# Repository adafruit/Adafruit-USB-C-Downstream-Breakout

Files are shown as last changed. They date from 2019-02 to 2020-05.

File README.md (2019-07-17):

## Adafruit USB C Breakout Board - Downstream Connection PCB

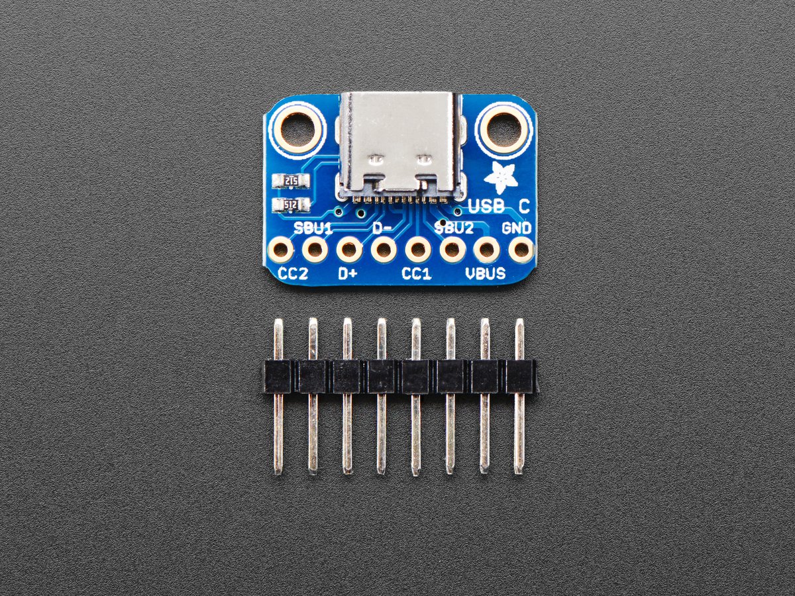
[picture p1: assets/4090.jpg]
<a href="http://www.adafruit.com/products/4090"><br/>
Click here to purchase one from the Adafruit shop</a>

PCB files for the Adafruit USB C Breakout Board - Downstream Connection. Format is EagleCAD schematic and board layout
* https://www.adafruit.com/product/4090

### Description

Throw out all those Mini and Micro B USB cables you have in a plastic bin - the next generation of USB connectors is here with **USB C!** You will start to see these connectors pop up on all sorts of devices, as the industry moves from micro B or lightening to the new standard. Well, at least until the next standard comes out

USB C features a symmetric/reversible connector, more data pins and higher current output capability. But, for most developers, the pin usage you know and love from older USB will work just fine. This breakout gives you all the basics you need and a resistor configuration that mimics classic USB 2.0 for a downstream connection

The two 5.1K resistors on the **CC1** pins indicate to the upstream port to provide 5V and up to 1.5A (whether the upstream can supply that much current depends on what you're connecting to.

For most usages, you can just connect **VBUS** to your 5V input, **GND** to ground, and **D+** and **D-** as you expect. You can monitor the CC and SBU pins to determine cable polarity, or send side-band data. Or leave them disconnected

[For more details, we like this introduction to USB C app note](http://ww1.microchip.com/downloads/en/appnotes/00001953a.pdf)
### License

Adafruit invests time and resources providing this open source design, please support Adafruit and open-source hardware by purchasing products from [Adafruit](https://www.adafruit.com)!

Designed by Limor Fried/Ladyada for Adafruit Industries.

Creative Commons Attribution/Share-Alike, all text above must be included in any redistribution. See license.txt for additional details.

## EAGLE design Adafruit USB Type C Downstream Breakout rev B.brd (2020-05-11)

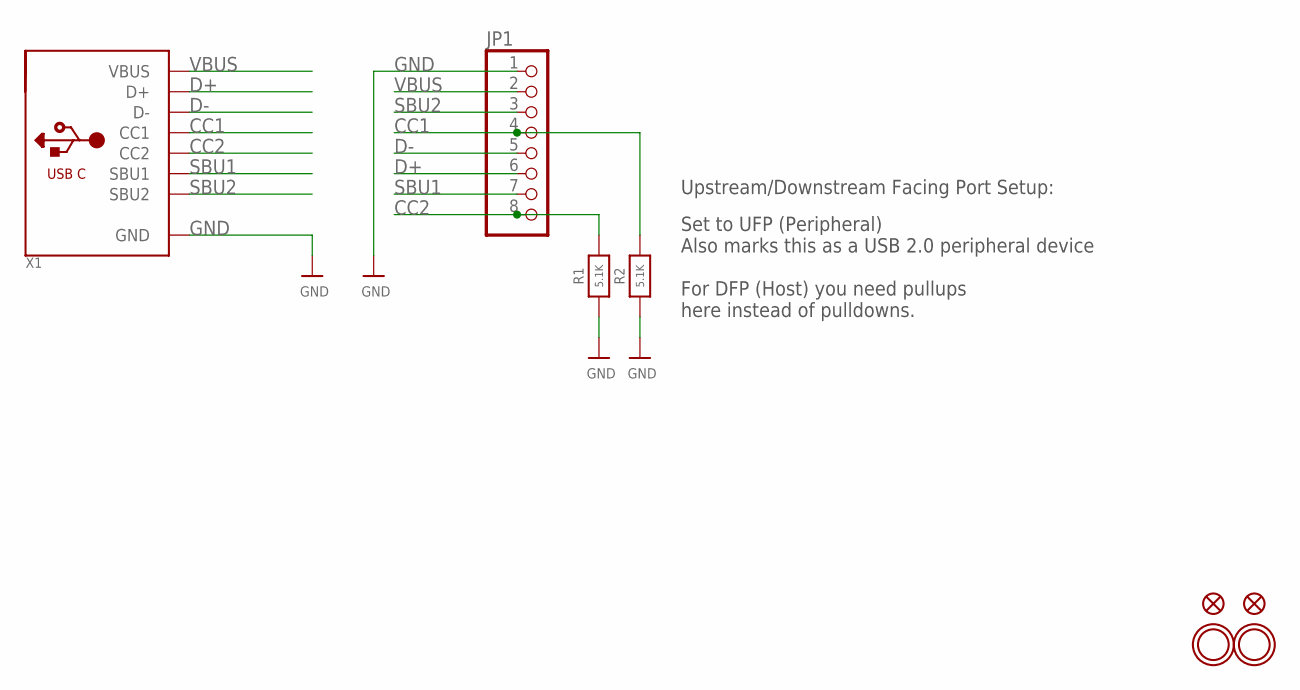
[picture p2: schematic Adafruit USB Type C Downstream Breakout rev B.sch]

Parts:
FID1, FID2: FIDUCIAL_1MM
JP1: HEADER-1X876MIL; 1X08_ROUND_76
R1, R2: 5.1K; 0603-NO
U$1, U$2: MOUNTINGHOLE2.5; MOUNTINGHOLE_2.5_PLATED
X1: USB_C; USB_C_CUSB31-CFM2AX-01-X

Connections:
CC1: JP1.4, R2.2, X1.A5 (CC1)
CC2: JP1.8, R1.2, X1.B5 (CC2)
D+: JP1.6, X1.A6 (D+), X1.B6 (D+)
D-: JP1.5, X1.A7 (D-), X1.B7 (D-)
GND: JP1.1, R1.1, R2.1, X1.A1B12 (GND), X1.B1A12 (GND)
SBU1: JP1.7, X1.A8 (SBU1)
SBU2: JP1.3, X1.B8 (SBU2)
VBUS: JP1.2, X1.A4B9 (VBUS), X1.B4A9 (VBUS)

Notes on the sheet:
Set to UFP (Peripheral) Also marks this as a USB 2.0 peripheral device For DFP (Host) you need pullups here instead of pulldowns.
Upstream/Downstream Facing Port Setup:

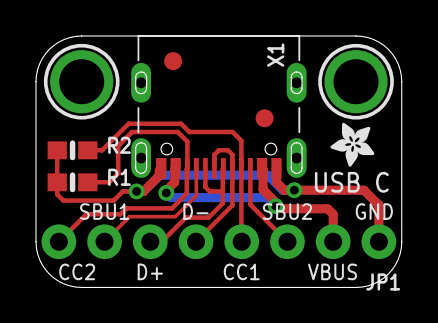
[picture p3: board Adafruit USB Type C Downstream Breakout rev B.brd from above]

Board: 2 copper layers, 20.3 x 14.0 mm, 10 parts (1 on the bottom side), 8 nets.

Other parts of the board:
U$3: ADAFRUIT_2.5MM
U$8: PCBFEAT-REV-040

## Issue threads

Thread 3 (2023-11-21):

Eagle CAD files present an error

rmwhite85, 2023-11-21:
When trying to open the .sch or .brd files in Eagle CAD (or similar application, e.g. EasyEDA) the programs indicate that the file is not valid.

EagleCAD error message (for both files) is:

> Error:
>
> line 8, column 156: This is not an EAGLE file.

EasyEDA error message is:

> Unexpected error while converting. Perhaps unsupported file type or program bug.

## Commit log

2019-02-06 Renamed files
    [Adafruit USB Type C Downstream Breakout rev A.brd, Adafruit USB Type C Downstream Breakout rev A.sch]
2019-07-17 updated to use cookiecutter for pcb repos
2020-05-11 updating to rev b to fix issue #1
    [Adafruit USB Type C Downstream Breakout rev B.brd, Adafruit USB Type C Downstream Breakout rev B.sch]

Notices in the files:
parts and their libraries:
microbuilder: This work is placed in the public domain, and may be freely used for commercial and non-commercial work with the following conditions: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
